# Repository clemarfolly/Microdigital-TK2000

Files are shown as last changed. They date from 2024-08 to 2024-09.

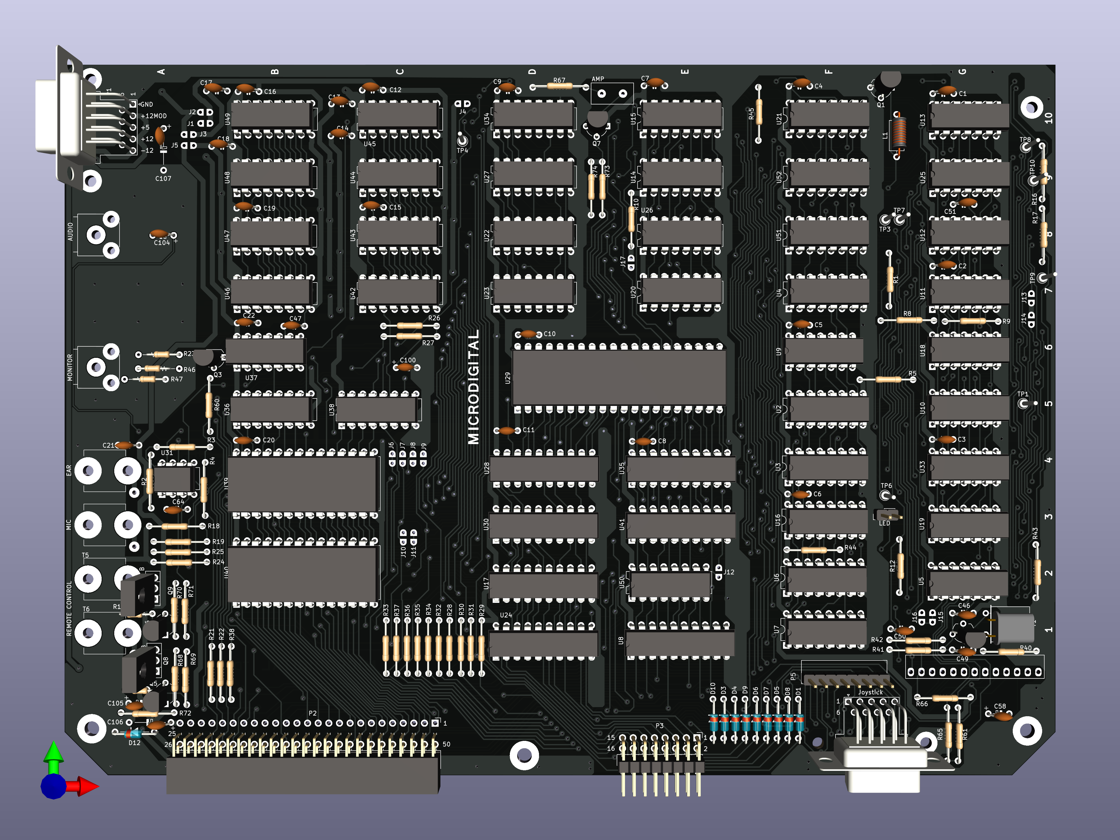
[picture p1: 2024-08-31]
Imagens/TK2000_f.png

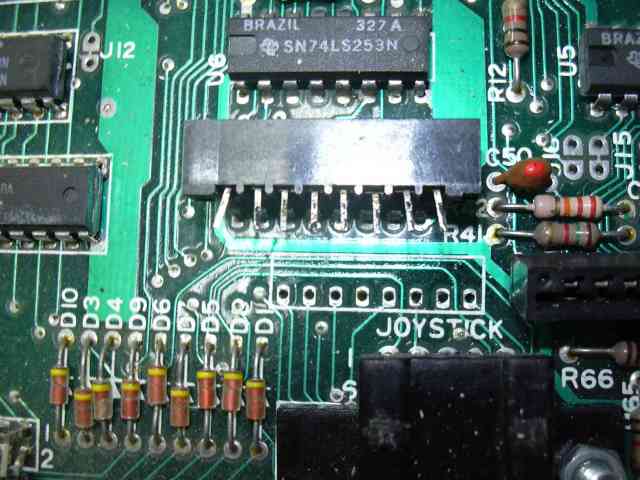
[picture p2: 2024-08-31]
Fotos/Original/6.jpg

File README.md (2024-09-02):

# Microdigital - TK2000

<p align="center">
    
</p>

A Microdigital Eletrônica Ltda foi uma das empresas pioneiras no mercado de microcomputadores no Brasil, tendo grande importância na popularização da informática durante a década de 1980. Fundada em 1979, a empresa se destacou por criar e distribuir uma série de microcomputadores compatíveis com modelos internacionais. A Microdigital se beneficiou da reserva de mercado imposta pelo governo brasileiro, o que levou a empresa a desenvolver produtos que atendessem à demanda interna por tecnologia, educação e entretenimento.

Entre os produtos está o TK2000, lançado oficialmente em 1984 após ser apresentado na Feira de Informática de 1983. Inspirado no Apple II, o TK2000 foi um microcomputador voltado para o mercado doméstico e educacional, parcialmente compatível com o software do Apple II, mas com algumas limitações em termos de hardware, o que o tornava mais acessível ao consumidor brasileiro. Equipado com uma CPU 6502, 16k de ROM e 64k de RAM, o TK2000 era, na verdade, um clone do Micro-Professor MPF-II, um modelo taiwanês fabricado pela Multitech (futura Acer). O sucesso do TK2000 consolidou a Microdigital como uma das líderes no mercado de microcomputadores no Brasil, contribuindo significativamente para a difusão da cultura computacional no país durante os anos 80. Em 1985, foi lançada uma versão aprimorada, o TK2000 II, que incluía uma opção de 128K de memória. O microcomputador foi descontinuado em 1987.

## Sobre essa reprodução

<p align="center">
    
</p>

A reprodução do projeto foi realizada sem acesso físico à placa original, com base em fotos encontradas na internet. Para isso, utilizou-se os software Sprint Layout e o KiCad para desenhar o esquema e a placa de circuito impresso. A réplica ainda não foi produzida, e seu funcionamento não foi validado. Agradecemos às pessoas que disponibilizaram as fotos e o esquema original, permitindo que esse trabalho fosse possível.

 ### Datalhes da placa
A placa é dupla face e o tamanho final ficou com 237x170 mm.

<p align="center">
  
  
</p>

### Comparação com a placa original
Embora eu não tenha tido acesso direto à placa original, me esforcei para que a recriação fosse a mais fiel possível. Algumas imagens de referência estavam em baixa resolução e precisaram ter suas proporções ajustadas, além de estarem com componentes e adesivos, o que dificultou a reprodução das trilhas que passavam por baixo deles.

<p align="center">
    
</p>

A parte de RF foi removida e no lugar colocada uma saída de áudio. Além disso, o jumper que conecta o pino 28 da ROM U39 ao pino 7 do 74LS244 foi integrado diretamente ao roteamento da placa, permetindo o uso de uma ROM 27C128.

### Para confecção

Na seção de releases desta página, você encontrará todos os arquivos necessários para a fabricação da placa: o gerber em formato zip, o esquema em PDF e a lista interativa de materiais em HTML. Basta enviar o arquivo zip para a sua fabricante de PCB de preferência.

### Chip customizado

A montagem requer a gravação de um chip PLD GAL16V8, o conteúdo está na pasta PAL. Mais detalhes em: 

https://www.facebook.com/groups/cidadedosclassicos/posts/5769043533153302/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

## Créditos

### Recriação da Placa: 

Clemar Folly Jr.

https://x.com/clemarfolly/ - https://www.facebook.com/clemarjr

### Fotos

Clube do TK90X

http://www.tk90x.com.br/Projetos_TK2000_clareamento.html

José Ferro - Recebido via E-mail

Tabajara Labs

http://tabalabs.com.br/tk2k/reparo_teclado/

Grupo Microdigital TK 2000 no Facebook

https://www.facebook.com/groups/2839171526116039/

Uma saída de som para o TK2000

https://www.victortrucco.com/TK/TK2000Som/TK2000Som

### Esquema

TK2000 - Esquema Elétrico Placa Principal - Datassette

https://datassette.org/manuais/hardware-tk-2000-microdigital-eletronica-manuais/tk2000-esquema-eletrico-placa-principal

#### Caso queira contribuir para que outras reproduções como esta sejam feitas, considere fazer uma doação.

Chave pix: clemarjr@gmail.com

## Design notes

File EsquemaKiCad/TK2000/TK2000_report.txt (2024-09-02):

PCB statistics report
=====================
- Date: 01/09/2024 15:54:08
- Project: TK2000
- Board name: TK2000

Board
-----
- Width: 236,8000 mm
- Height: 169,8100 mm
- Area: 40103,0117 mm²

Pads
----
- Through hole: 1244
- SMD: 0
- Connector: 0
- NPTH: 1

Vias
----
- Through vias: 583
- Blind/buried: 0
- Micro vias: 0

Components
----------

| | Front Side | Back Side | Total |
|---|---|---|---|
|THT: | 195 | 0 | 195 |
|SMD: | 0 | 0 | 0 |
|Unspecified:  | 9 | 2 | 11 |
|Total: | 204 | 2 | 206 |

Drill holes
-----------

| Count | Shape | X Size | Y Size | Plated | Via/Pad | Start Layer | Stop Layer |
|---|---|---|---|---|---|---|---|
| 958 | Round | 0,8000 mm | 0,8000 mm | PTH | Pad | F.Cu | B.Cu |
| 576 | Round | 0,6000 mm | 0,6000 mm | PTH | Via | F.Cu | B.Cu |
| 125 | Round | 1,0000 mm | 1,0000 mm | PTH | Pad | F.Cu | B.Cu |
| 106 | Round | 0,7000 mm | 0,7000 mm | PTH | Pad | F.Cu | B.Cu |
| 34 | Round | 0,7620 mm | 0,7620 mm | PTH | Pad | F.Cu | B.Cu |
| 8 | Round | 2,5000 mm | 2,5000 mm | PTH | Pad | F.Cu | B.Cu |
| 7 | Round | 0,8000 mm | 0,8000 mm | PTH | Via | F.Cu | B.Cu |
| 4 | Round | 2,7000 mm | 2,7000 mm | PTH | Pad | F.Cu | B.Cu |
| 4 | Round | 1,8000 mm | 1,8000 mm | PTH | Pad | F.Cu | B.Cu |
| 3 | Round | 3,5000 mm | 3,5000 mm | PTH | Pad | F.Cu | B.Cu |
| 2 | Round | 2,2000 mm | 2,2000 mm | PTH | Pad | F.Cu | B.Cu |
| 1 | Round | 2,7000 mm | 2,7000 mm | NPTH | Pad | F.Cu | B.Cu |

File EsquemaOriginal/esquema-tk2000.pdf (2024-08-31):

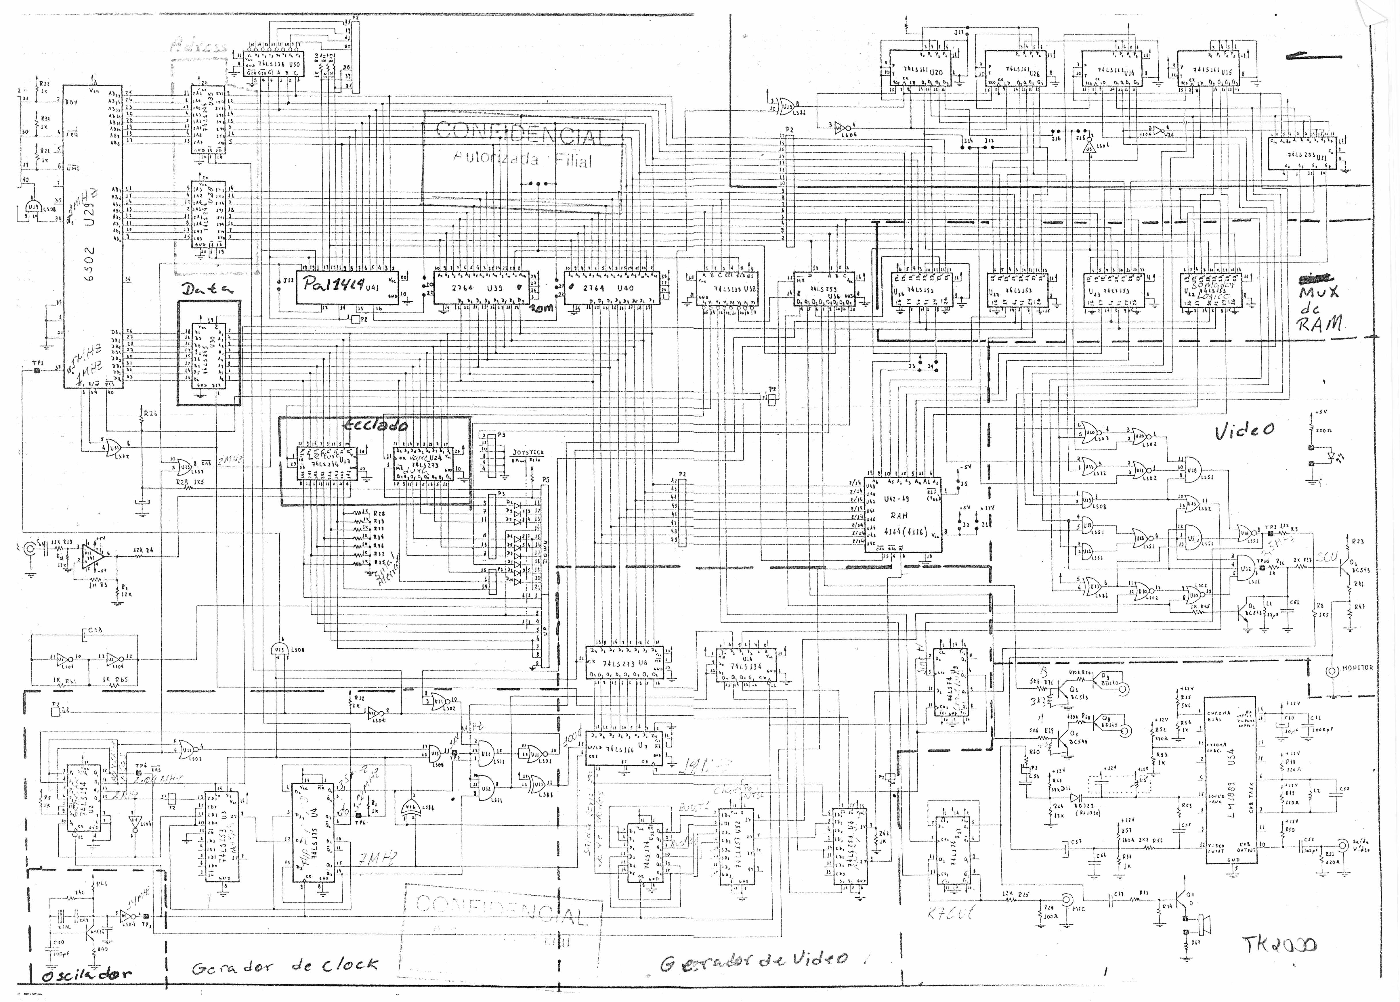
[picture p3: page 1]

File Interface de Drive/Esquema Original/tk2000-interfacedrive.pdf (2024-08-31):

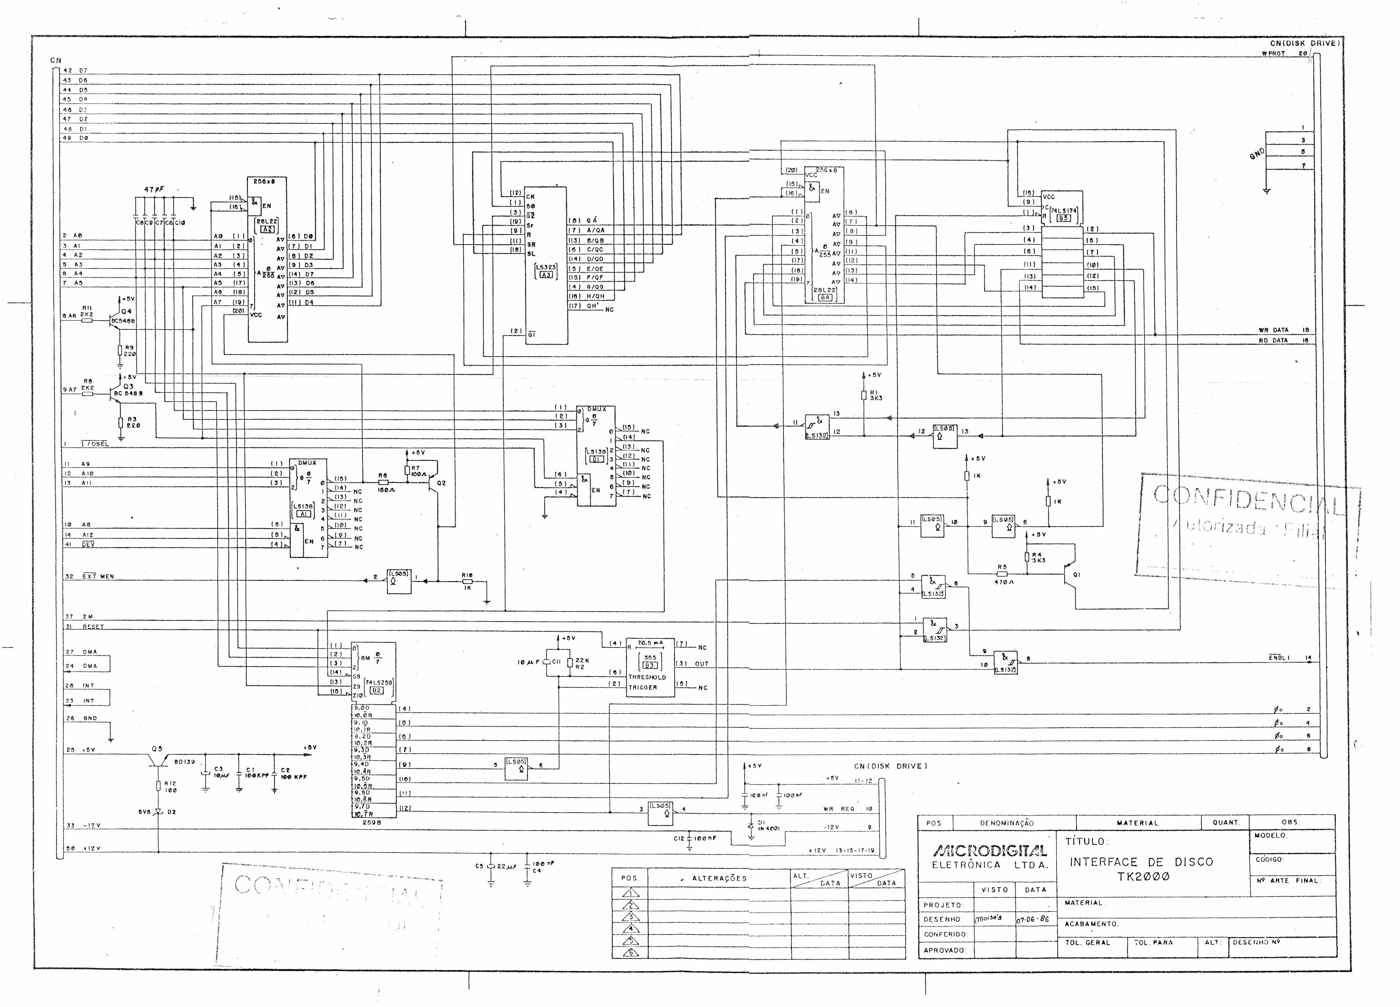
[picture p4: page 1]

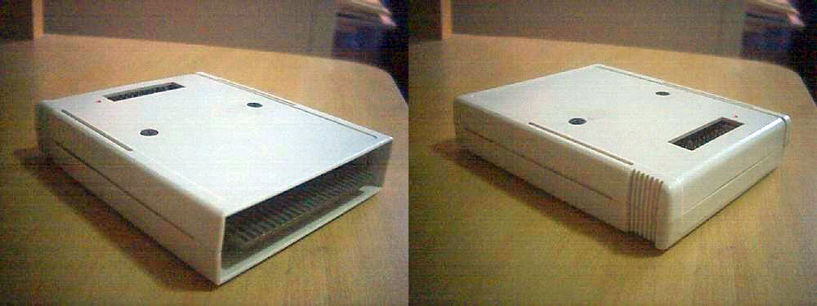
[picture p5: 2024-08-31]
Interface de Drive/Fotos/cartucho_interface.jpg

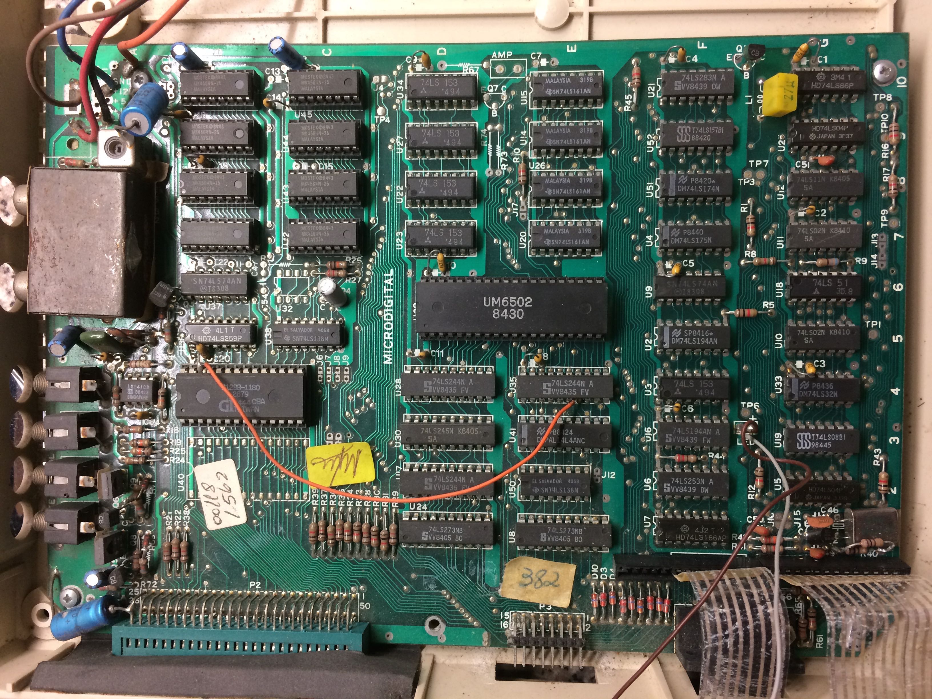
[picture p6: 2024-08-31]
Fotos/Original/tk2000-1.jpg

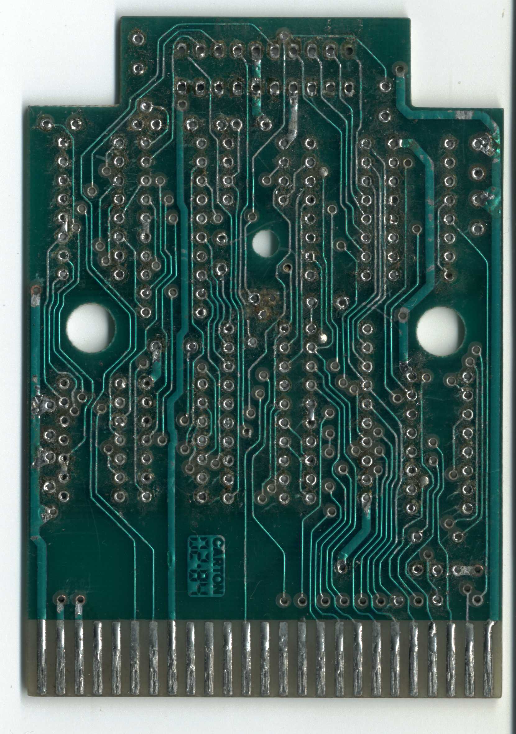
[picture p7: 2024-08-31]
Interface de Drive/Fotos/placa_drive_ls_vazia.jpg

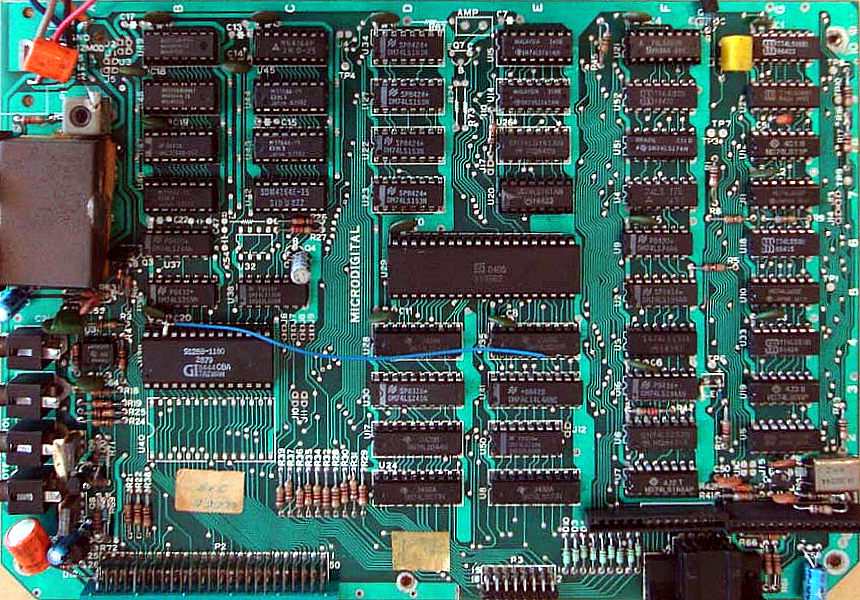
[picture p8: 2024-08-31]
Fotos/Corrigido/tk2000_pre_f.png

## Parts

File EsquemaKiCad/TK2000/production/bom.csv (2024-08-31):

Designator | Footprint | Quantity | Value | LCSC Part #
C1, C10, C11, C12, C13, C14, C15, C16, C17, C18, C19, C2, C20, C21, C22, C3, C4, C5, C6, C7, C8, C9 | C_Disc_D4.3mm_W1.9mm_P5.00mm | 22 | 0.1
C100, C58 | C_Polarized_P5.00mm | 2 | C_Polarized_Small
C104 | C_Polarized_P5.00mm | 1 | 1uF
C105 | C_Polarized_P5.00mm | 1 | 47uF
C106, C107 | C_Polarized_P10.00mm | 2 | 100uF
C46, C47, C49, C50, C51 | C_Disc_D4.3mm_W1.9mm_P5.00mm | 5 | C_Small
C64 | C_Disc_D4.3mm_W1.9mm_P5.00mm | 1 | ?
D1, D10, D3, D4, D5, D6, D7, D8, D9 | Diodo_9.38mm | 9 | D_Small
D12 | Diodo_9.38mm | 1 | 5V1
D13 | PinHeader_1x02_P2.54mm_Vertical | 1 | LED
H1, H2, H3 | MountingHole_3.5mm_Pad | 3 | MountingHole_Pad
H4, H6, H7, H8 | MountingHole_2.7mm_Pad | 4 | MountingHole_Pad
H5 | MountingHole_2.7mm | 1 | MountingHole_Pad
J1, J10, J14, J16, J3, J4, J5, J7, J9 | Jumper_Open | 9 | SolderJumper_2_Open
J100 | DSUB-9_Male_Horizontal_P2.77x2.54mm_EdgePinOffset9.40mm | 1 | Joystick
J11, J12, J6, J8 | Jumper_Bridged | 4 | SolderJumper_2_Open
J13, J15 | Jumper_Bridged | 2 | ~
J17 | Jumper_Open | 1 | SolderJumper_2_Open_Small
J2 | Jumper_Open | 1 | TK2000:Jumper_Open
L1 | L_Axial_L7.0mm_D3.3mm_P10.16mm_Horizontal_Fastron_MICC | 1 | 47uH
LS1 | Connector_AMP | 1 | AMP
P1 | DSUB-9_Male_Horizontal_P2.77x2.54mm_EdgePinOffset9.40mm | 1 | POWER
P2 | PinSocket_2x25_P2.54mm_Horizontal | 1 | Conector de Expansão
P3 | PinHeader_2x08_P2.54mm_Horizontal | 1 | P3
P5 | Connector_P5 | 1 | Conector_P5
Q1, Q3, Q5, Q6, Q7 | TO-92_Wide | 5 | BC548
Q2 | TO-92_Wide_Invert | 1 | BF494B
Q8, Q9 | TO-126-3_Vertical | 2 | BD140
R1, R10, R12, R16, R2, R21, R22, R26, R28, R29, R30, R31, R32, R33, R34, R35, R36, R37, R38, R43, R45, R5, R61, R65, R66 | Resistor_P12.7mm_Horizontal | 25 | 1k
R169, R171 | Resistor_P5.08mm_Vertical | 2 | 3k3
R17 | Resistor_P12.7mm_Horizontal | 1 | 2k
R18, R19, R25, R4, R9 | Resistor_P12.7mm_Horizontal | 5 | 12k
R23, R46, R47 | Resistor_P9.8mm_Horizontal | 3 | 1k
R24 | Resistor_P12.7mm_Horizontal | 1 | 100
R27, R8 | Resistor_P12.7mm_Horizontal | 2 | 1k5
R3 | Resistor_P12.7mm_Horizontal | 1 | 1M
R40, R41, R42 | Resistor_P12.7mm_Horizontal | 3 | 47
R44 | Resistor_P12.7mm_Horizontal | 1 | 220
R60 | Resistor_P12.7mm_Horizontal | 1 | 560
R67, R72, R73, R74 | Resistor_P12.7mm_Horizontal | 4 | ?
R68, R70 | Resistor_P12.7mm_Horizontal | 2 | 470
R69, R71 | Resistor_P12.7mm_Horizontal | 2 | 5k6
T2 | RCA_AV-8,4-5A | 1 | MONITOR
T3 | J2_Mono_Panel | 1 | EAR
T4 | J2_Mono_Panel | 1 | MIC
T5 | J2_Mono_Panel | 1 | B - Remote
T6 | J2_Mono_Panel | 1 | A - Remote
T7 | RCA_AV-8,4-5A | 1 | AUDIO
TP1, TP10, TP3, TP6, TP7, TP8, TP9 | Pin_D1.0mm_L10.0mm | 7 | TestPoint_Small
TP4 | Pin_D1.0mm_L10.0mm | 1 | ~{CAS}
U10, U11 | DIP-14_W7.62mm | 2 | 74LS02
U12 | DIP-14_W7.62mm | 1 | 74LS11
U13 | DIP-14_W7.62mm | 1 | 74LS86
U14, U15, U20, U26 | DIP-16_W7.62mm | 4 | 74LS161
U16, U2 | DIP-16_W7.62mm | 2 | 74LS194
U17, U28, U35 | DIP-20_W7.62mm | 3 | 74LS244
U18 | DIP-14_W7.62mm | 1 | 74LS51
U19 | DIP-14_W7.62mm | 1 | 74LS08
U21 | DIP-16_W7.62mm | 1 | 74LS283
U22, U23, U27, U3, U34 | DIP-16_W7.62mm | 5 | 74LS153
U24, U8 | DIP-20_W7.62mm | 2 | 74LS273
U25, U5 | DIP-14_W7.62mm | 2 | 74LS04
U29 | DIP-40_W15.24mm | 1 | 6502
U30 | DIP-20_W7.62mm | 1 | 74LS245
U31 | DIP-8_W7.62mm | 1 | LM741
U33 | DIP-14_W7.62mm | 1 | 74LS32
U36 | DIP-16_W7.62mm | 1 | 74LS259
U37, U9 | DIP-14_W7.62mm | 2 | 74LS74
U38, U50 | DIP-16_W7.62mm | 2 | 74LS138
U39, U40 | DIP-28_W15.24mm | 2 | 2764
U4 | DIP-16_W7.62mm | 1 | 74LS175
U41 | DIP-20_W7.62mm | 1 | PAL14L4
U42 | DIP-16_W7.62mm | 1 | 4116_U42
U43 | DIP-16_W7.62mm | 1 | 4116_U43
U44, U45, U46, U47 | DIP-16_W7.62mm | 4 | 4116_U47
U48, U49 | DIP-16_W7.62mm | 2 | 4116
U51 | DIP-16_W7.62mm | 1 | 74LS174
U52 | DIP-16_W7.62mm | 1 | 74LS157
U6 | DIP-16_W7.62mm | 1 | 74LS253
U7 | DIP-16_W7.62mm | 1 | 74LS166
Y1 | Crystal_HC52-U_Horizontal | 1 | Crystal

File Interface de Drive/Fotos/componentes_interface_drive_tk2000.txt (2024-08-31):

Q1 - BC558

Q2 - BC557

U1 - 74259

U2 - 7400

U3 - 555

U4 - 74174

U5 - 7405

não existe U6 no layout

U7 - 74138

U8 - N82S135N (PROM,256X8)

U9 - 74323

U10 - N82S135N (PROM,256X8)

U11 - 74138

C1 - 10uFx25V (lado positivo em R2)

C2 - 100nF (104)

C3 - 10uFx25V

C4 (próx. a U11) - 100nF (104)

C5 (próx. a U11) - 10uFx25V
C
4 (próx. a C6) - 47pF (470)

C5 (próx. a C6) - 47pF (470)

C6 - 47pF (470)
C7 - 47pF (470)

R1 - 3K3 (LR, LR, VM)

R2 - 22K (VM, VM, LR)

não existe R3 no layout

R4 - 3K3 (LR, LR, VM)

R5 - 470R (AM, RX, MR) 

R6 (próx. a U11) - 180
R (MR, CZ, MR)

R6 (próx. a R7) - vazio

R7 - 100R (MR, PT, MR)

não existe R8 no layout

não existe R9 no layout

R10 - 1K (MR, PT, VM)

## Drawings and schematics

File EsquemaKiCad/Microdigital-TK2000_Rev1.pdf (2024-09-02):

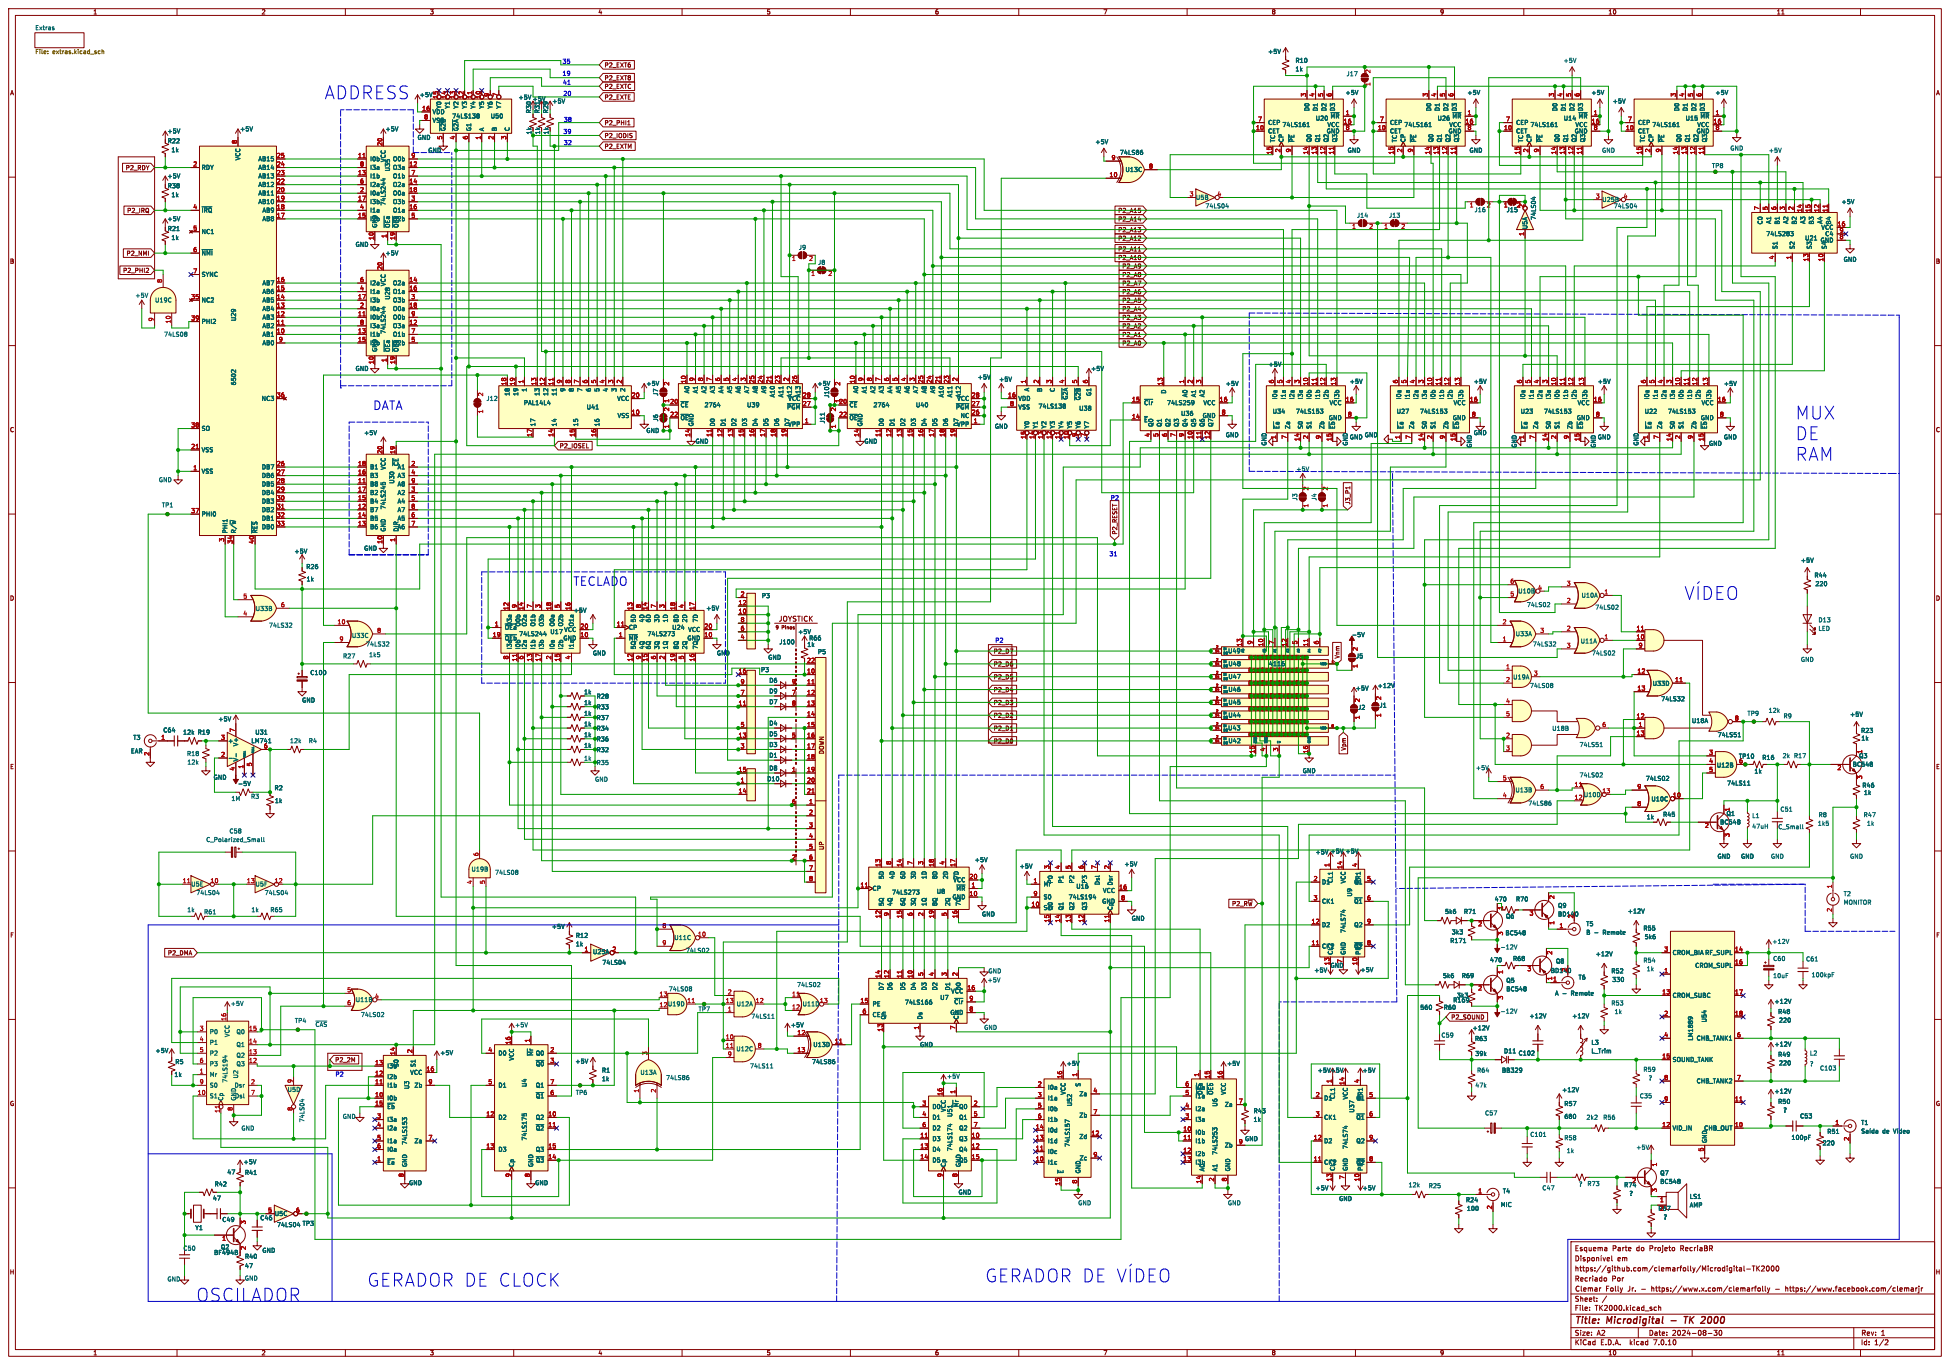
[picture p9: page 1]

3 DB3 30 DB2 31 DB1 32 DB0 33 R/~{W} 34 NC2 35 NC3 36 PHI0 37 SO 38 PHI2 39 ~{IRQ} 4 ~{RES} 40 NC1 5 ~{NMI} 6 SYNC 7 VCC

2 ~{CE} 20 A10 21 ~{OE} 22 A11 23 A9 24 A8 25 NC 26 ~{PGM} 27 VCC 28 A7

9 U22 74LS153 GND ~{Ea} 1 I0b 10 I1b 11 I2b 12 I3b 13 S0 14 ~{Eb} 15 VCC

þÿSaídae þÿVídeo GND

5 CE 6 Clk 7 GND 8 ~{Clr}9 Q1 BC548

5 CE 6 Clk 7 GND 8 ~{Clr} U7 9

8 Zb 9 GND U4 74LS175 ~{Mr}1 Q2 10 ~{Q2}11 D2 12 D3 13 ~{Q3}14 Q3 15 VCC 16 Q0 2 ~{Q0}3 D0 4 D1 5 ~{Q1}6 Q1 7 GND

8 Zc 9 +5V GND U51 74LS174 ~{Mr}1 Q3 10 D3 11 Q4 12 D4 13 D5 14 Q5 15 VCC 16 Q0 2 D0 3 D1 4 Q1 5 D2 6 Q2 7 GND

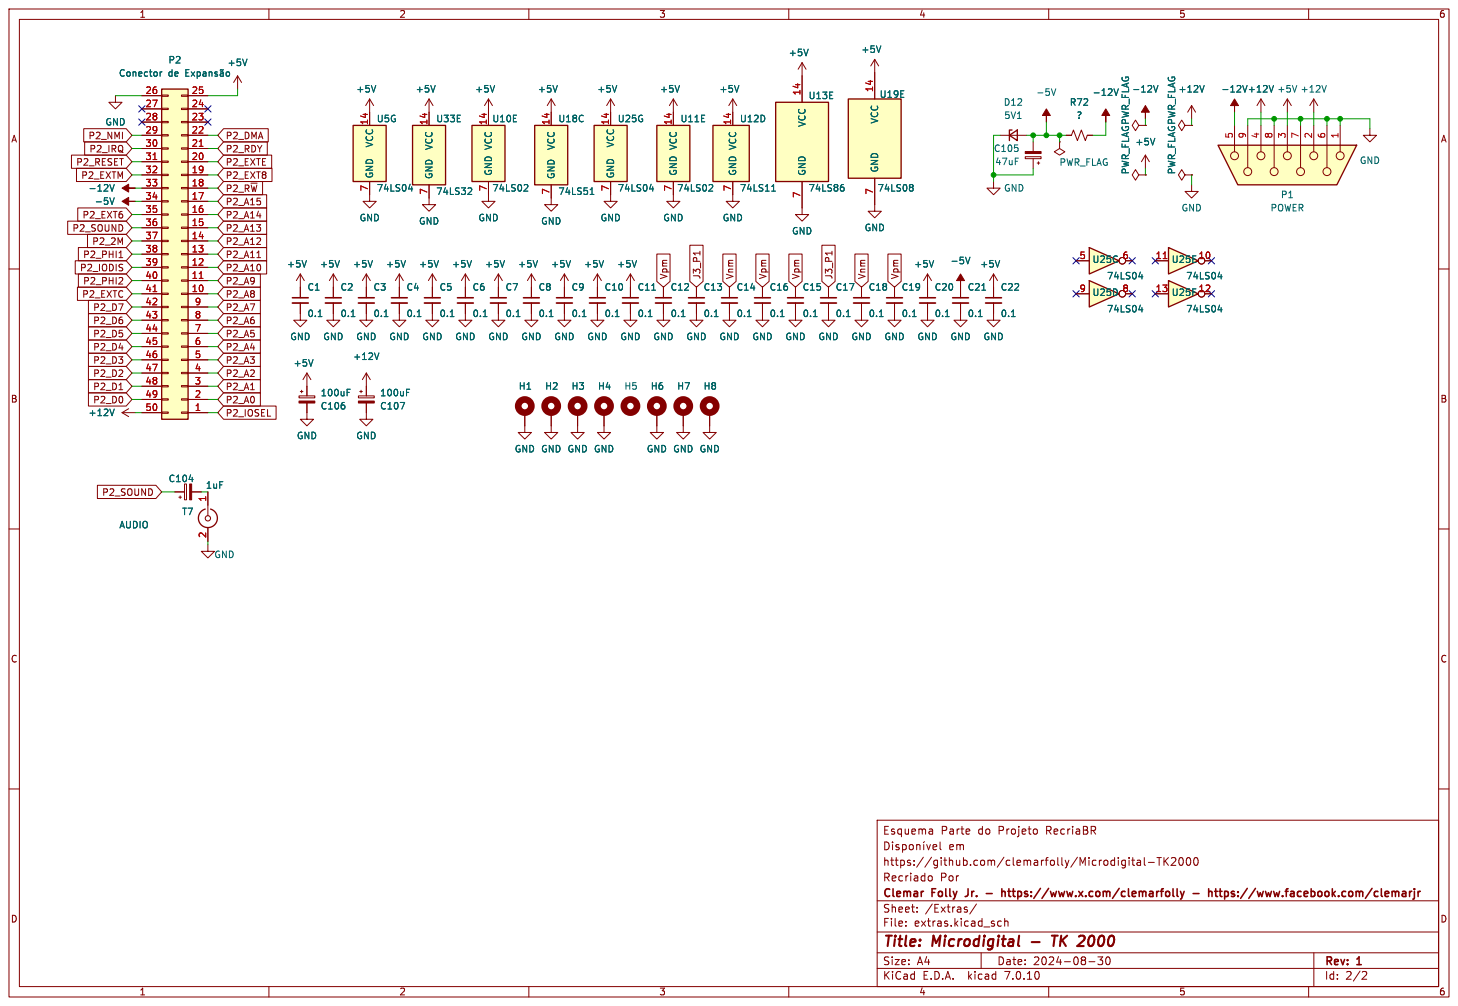
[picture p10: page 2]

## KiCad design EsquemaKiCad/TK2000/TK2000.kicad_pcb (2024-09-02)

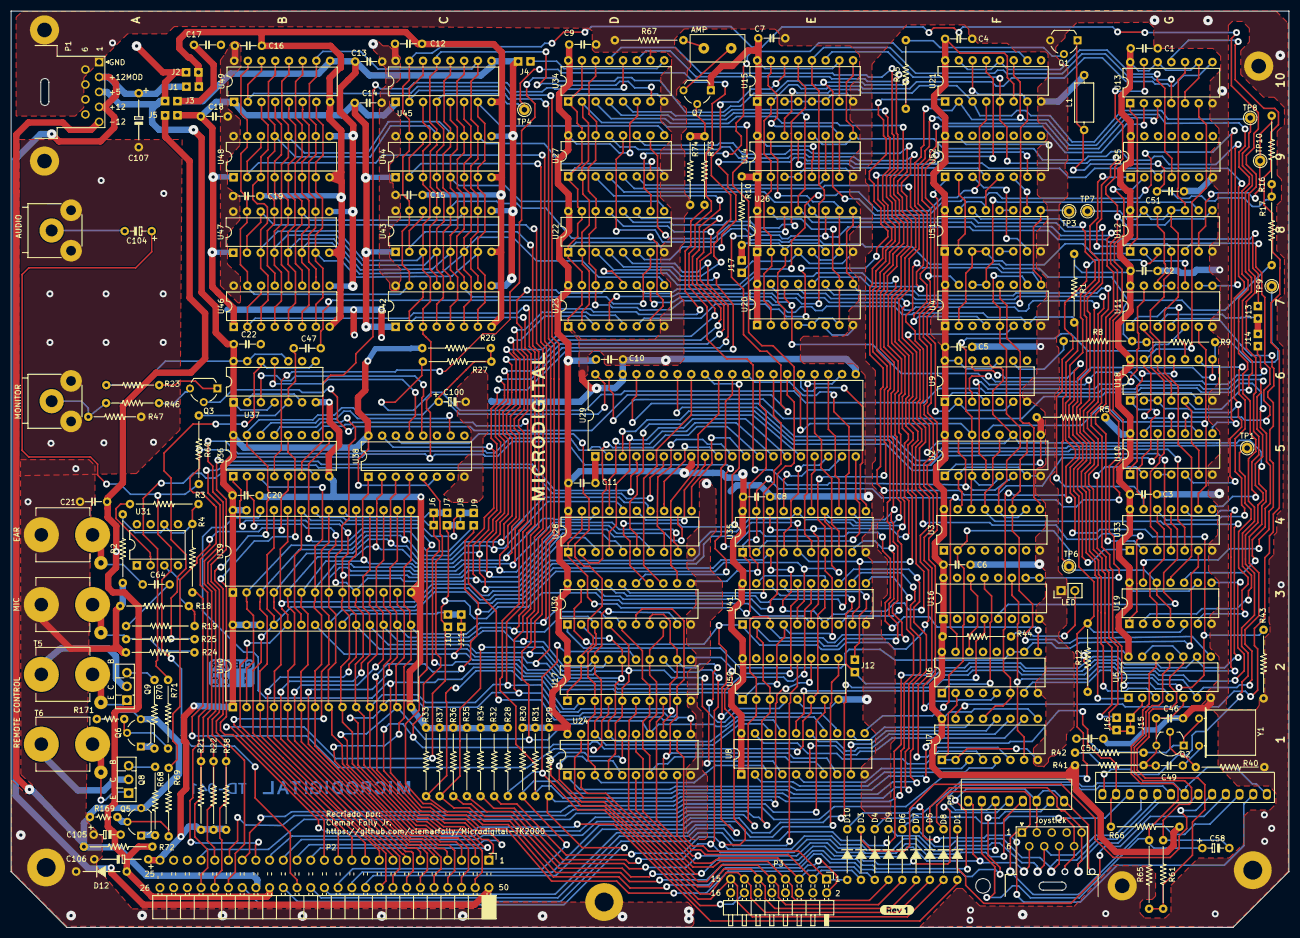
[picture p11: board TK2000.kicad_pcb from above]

Board: 2 copper layers, 236.8 x 169.8 mm, 204 parts (0 on the bottom side), 253 nets.

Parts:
C1, C2, C3, C4, C5, C6, C7, C8, C9, C10, C11, C12, C13, C14, C15, C16, C17, C18, C19, C20, C21, C22: 0.1; C_Disc_D4.3mm_W1.9mm_P5.00mm
C46, C47, C49, C50, C51: C_Small; C_Disc_D4.3mm_W1.9mm_P5.00mm
C58, C100: C_Polarized_Small; C_Polarized_P5.00mm
C64: ?; C_Disc_D4.3mm_W1.9mm_P5.00mm
C104: 1uF; C_Polarized_P5.00mm
C105: 47uF; C_Polarized_P5.00mm
C106, C107: 100uF; C_Polarized_P10.00mm
D1, D3, D4, D5, D6, D7, D8, D9, D10: D_Small; Diodo_9.38mm
D12: 5V1; Diodo_9.38mm
D13: LED; PinHeader_1x02_P2.54mm_Vertical
H1, H2, H3: MountingHole_Pad; MountingHole_3.5mm_Pad
H4, H6, H7, H8: MountingHole_Pad; MountingHole_2.7mm_Pad
H5: MountingHole_Pad; MountingHole_2.7mm
J1, J3, J4, J5, J7, J9, J10, J14, J16: SolderJumper_2_Open; Jumper_Open
J2: TK2000:Jumper_Open; Jumper_Open
J6, J8, J11, J12: SolderJumper_2_Open; Jumper_Bridged
J13, J15: Jumper_Bridged
J17: SolderJumper_2_Open_Small; Jumper_Open
J100: Joystick; DSUB-9_Male_Horizontal_P2.77x2.54mm_EdgePinOffset9.40mm
L1: 47uH; L_Axial_L7.0mm_D3.3mm_P10.16mm_Horizontal_Fastron_MICC
LS1: AMP; Connector_AMP
P1: POWER; DSUB-9_Male_Horizontal_P2.77x2.54mm_EdgePinOffset9.40mm
P2: Conector de Expansão; PinSocket_2x25_P2.54mm_Horizontal
P3: P3; PinHeader_2x08_P2.54mm_Horizontal
P5: Conector_P5; Connector_P5
Q1, Q3, Q5, Q6, Q7: BC548; TO-92_Wide
Q2: BF494B; TO-92_Wide_Invert
Q8, Q9: BD140; TO-126-3_Vertical
R1, R2, R5, R10, R12, R16, R21, R22, R26, R28, R29, R30, R31, R32, R33, R34, R35, R36, R37, R38, R43, R45, R61, R65, R66: 1k; Resistor_P12.7mm_Horizontal
R3: 1M; Resistor_P12.7mm_Horizontal
R4, R9, R18, R19, R25: 12k; Resistor_P12.7mm_Horizontal
R8, R27: 1k5; Resistor_P12.7mm_Horizontal
R17: 2k; Resistor_P12.7mm_Horizontal
R23, R46, R47: 1k; Resistor_P9.8mm_Horizontal
R24: 100; Resistor_P12.7mm_Horizontal
R40, R41, R42: 47; Resistor_P12.7mm_Horizontal
R44: 220; Resistor_P12.7mm_Horizontal
R60: 560; Resistor_P12.7mm_Horizontal
R67, R72, R73, R74: ?; Resistor_P12.7mm_Horizontal
R68, R70: 470; Resistor_P12.7mm_Horizontal
R69, R71: 5k6; Resistor_P12.7mm_Horizontal
R169, R171: 3k3; Resistor_P5.08mm_Vertical
T2: MONITOR; RCA_AV-8,4-5A
T3: EAR; J2_Mono_Panel
T4: MIC; J2_Mono_Panel
T5: B - Remote; J2_Mono_Panel
T6: A - Remote; J2_Mono_Panel
T7: AUDIO; RCA_AV-8,4-5A
TP1, TP3, TP6, TP7, TP8, TP9, TP10: TestPoint_Small; Pin_D1.0mm_L10.0mm
TP4: ~{CAS}; Pin_D1.0mm_L10.0mm
U2, U16: 74LS194; DIP-16_W7.62mm
U3, U22, U23, U27, U34: 74LS153; DIP-16_W7.62mm
U4: 74LS175; DIP-16_W7.62mm
U5, U25: 74LS04; DIP-14_W7.62mm
U6: 74LS253; DIP-16_W7.62mm
U7: 74LS166; DIP-16_W7.62mm
U8, U24: 74LS273; DIP-20_W7.62mm
U9, U37: 74LS74; DIP-14_W7.62mm
U10, U11: 74LS02; DIP-14_W7.62mm
U12: 74LS11; DIP-14_W7.62mm
U13: 74LS86; DIP-14_W7.62mm
U14, U15, U20, U26: 74LS161; DIP-16_W7.62mm
U17, U28, U35: 74LS244; DIP-20_W7.62mm
U18: 74LS51; DIP-14_W7.62mm
U19: 74LS08; DIP-14_W7.62mm
U21: 74LS283; DIP-16_W7.62mm
U29: 6502; DIP-40_W15.24mm
U30: 74LS245; DIP-20_W7.62mm
U31: LM741; DIP-8_W7.62mm
U33: 74LS32; DIP-14_W7.62mm
U36: 74LS259; DIP-16_W7.62mm
U38, U50: 74LS138; DIP-16_W7.62mm
U39, U40: 2764; DIP-28_W15.24mm
U41: PAL14L4; DIP-20_W7.62mm
U42: 4116_U42; DIP-16_W7.62mm
U43: 4116_U43; DIP-16_W7.62mm
U44, U45, U46, U47: 4116_U47; DIP-16_W7.62mm
U48, U49: 4116; DIP-16_W7.62mm
U51: 74LS174; DIP-16_W7.62mm
U52: 74LS157; DIP-16_W7.62mm
Y1: Crystal; Crystal_HC52-U_Horizontal
kibuzzard-66D4FA69: G***; kibuzzard-66D4FA69

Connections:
+5V: C1.1, C2.1, C3.1, C4.1, C5.1, C6.1, C7.1, C8.1, C9.1, C10.1, C11.1, C20.1, C22.1, C106.1, J2.2 (B), J3.2 (B), P1.3, P2.25, Q7.1 (C), R1.1, R5.2, R10.1, R12.1, R21.1, R22.1, R23.2, R26.1, R29.1, R30.1, R31.1, R38.1, R41.1, R44.2, R66.1, U2.16 (VCC), U3.16 (VCC), U4.1 (~Mr), U4.16 (VCC), U5.14 (VCC), U6.16 (VCC), U7.9 (~Clr), U7.16 (VCC), U8.1 (~MR), U8.20 (VCC), U9.1 (CL1), U9.4 (PR1), U9.10 (PR2), U9.13 (CL2), U9.14 (VCC), U10.14 (VCC), U11.14 (VCC), U12.14 (VCC), U13.5, U13.9, U13.12, U13.14 (VCC), U14.1 (~MR), U14.5 (D2), U14.16 (VCC), U15.1 (~MR), U15.7 (CEP), U15.10 (CET), U15.16 (VCC), U16.1 (Mr), U16.16 (VCC), U17.20 (VCC), U18.14 (VCC), U19.9, U19.14 (VCC), U20.1 (~MR), U20.16 (VCC), U21.6 (B1), U21.16 (VCC), U22.16 (VCC), U23.16 (VCC), U24.20 (VCC), U25.14 (VCC), U26.1 (~MR), U26.16 (VCC), U27.16 (VCC), U28.20 (VCC), U29.8 (VCC), U30.20 (VCC), U31.7 (V+), U33.14 (VCC), U34.6 (I0a), U34.16 (VCC), U35.20 (VCC), U36.16 (VCC), U37.1 (CL1), U37.4 (PR1), U37.10 (PR2), U37.13 (CL2), U37.14 (VCC), U38.6 (G1), U38.16 (VDD), U39.1 (VPP), U39.27 (~PGM), U39.28 (VCC), U40.1 (VPP), U40.26 (NC), U40.27 (~PGM), U40.28 (VCC), U41.20 (VCC), U50.16 (VDD), U51.1 (~Mr), U51.16 (VCC), U52.16 (VCC)
+12V: C107.1, J1.2 (B), P1.2, P1.4, P2.50
-5V: C21.1, C105.2, D12.2 (A), J5.2 (B), P2.34, R72.1, U31.4 (V-)
-12V: P1.5, P2.33, Q5.3 (E), Q6.3 (E), R72.2, R169.1, R171.2
GND: C1.2, C2.2, C3.2, C4.2, C5.2, C6.2, C7.2, C8.2, C9.2, C10.2, C11.2, C12.2, C13.2, C14.2, C15.2, C16.2, C17.2, C18.2, C19.2, C20.2, C21.2, C22.2, C46.2, C50.1, C51.2, C100.2, C105.1, C106.2, C107.2, D12.1 (K), D13.1 (K), H1.1, H2.1, H3.1, H4.1, H6.1, H7.1, H8.1, J17.1 (A), L1.2, P1.1, P1.6, P1.7, P1.8, P1.9, P2.26, P3.4, P3.6, P3.8, P3.10, P3.12, Q1.3 (E), R2.1, R18.1, R24.1, R28.1, R32.1, R33.1, R34.1, R35.1, R36.1, R37.1, R40.1, R43.2, R47.1, R67.1, R74.1, T2.2 (Ext), T3.2 (Ext), T4.2 (Ext), T7.2 (Ext), U2.2 (Dsr), U2.7 (Dsl), U2.8 (GND), U3.8 (GND), U3.15 (~Eb), U4.8 (GND), U5.7 (GND), U6.2 (A1), U6.8 (GND), U7.1 (Ds), U7.2 (D0), U7.8 (GND), U8.10 (GND), U9.7 (GND), U10.7 (GND), U11.7 (GND), U12.7 (GND), U13.7 (GND), U14.3 (D0), U14.4 (D1), U14.8 (GND), U15.3 (D0), U15.4 (D1), U15.5 (D2), U15.6 (D3), U15.8 (GND), U16.8 (GND), U17.10 (GND), U18.7 (GND), U19.7 (GND), U20.6 (D3), U20.8 (GND), U21.8 (GND), U22.1 (~Ea), U22.8 (GND), U22.15 (~Eb), U23.1 (~Ea), U23.8 (GND), U23.15 (~Eb), U24.10 (GND), U25.7 (GND), U26.4 (D1), U26.8 (GND), U27.1 (~Ea), U27.8 (GND), U27.15 (~Eb), U28.10 (GND), U29.1 (VSS), U29.21 (VSS), U29.38 (SO), U30.10 (GND), U33.7 (GND), U34.1 (~Ea), U34.8 (GND), U34.10 (I0b), U34.15 (~Eb), U35.10 (GND), U36.8 (GND), U37.7 (GND), U38.8 (VSS), U39.14 (GND), U40.14 (GND), U41.10 (VSS), U42.16 (GND), U43.16, U44.16, U45.16, U46.16, U47.16, U48.16, U49.16, U50.5 (~G2B), U50.8 (VSS), U51.8 (GND), U52.8 (GND), U52.15 (~E)
J3_P1: C13.1, C17.1, J3.1 (A), J4.1 (A), U42.9, U43.9, U44.9, U45.9, U46.9, U47.9, U48.9, U49.9
unnamed: C47.2, R73.1
unnamed: C49.1, Y1.1
unnamed: C58.1, P5.2, R65.2, U5.12
unnamed: C58.2, R61.1, U5.11
unnamed: C64.2, R19.2
unnamed: D1.2 (A), U36.12 (Q7)
unnamed: D1.1 (K), P5.18
unnamed: D3.2 (A), P3.3, U24.9 (4Q)
unnamed: D3.1 (K), P5.17
unnamed: D4.2 (A), P3.5, U24.15 (6Q)
unnamed: D4.1 (K), P5.15, P5.21
unnamed: D5.2 (A), P3.13, U24.5 (2Q)
unnamed: D5.1 (K), J100.5, P5.16
unnamed: D6.2 (A), P3.9, U24.2 (1Q)
unnamed: D6.1 (K), J100.9, P5.11
unnamed: D7.2 (A), P3.11, U24.19 (8Q)
unnamed: D7.1 (K), J100.8, P5.13
unnamed: D8.2 (A), P3.15, U24.16 (7Q)
unnamed: D8.1 (K), J100.1, P5.19
unnamed: D9.2 (A), P3.7, U24.6 (3Q)
unnamed: D9.1 (K), J100.7, P5.12
unnamed: D10.2 (A), P3.1, U24.12 (5Q)
unnamed: D10.1 (K), P5.20
unnamed: D13.2 (A), R44.1
unnamed: J4.2 (B), U34.9 (Zb)
unnamed: J6.1 (A), J6.2 (B), J7.1 (A), U39.20 (~CE), U39.22 (~OE), U41.15
unnamed: J10.1 (A), J11.1 (A), J11.2 (B), U40.20 (~CE), U40.22 (~OE), U41.16
unnamed: J12.1 (A), U41.17
unnamed: J12.2 (B), U33.10, U41.18
unnamed: J13.1 (A), J14.2 (B), U11.3
unnamed: J13.2 (B), U26.11 (Q3), U27.12 (I2b)
unnamed: J14.1 (A), U5.1, U20.14 (Q0), U23.10 (I0b)
unnamed: J15.1 (A), J15.2 (B), J16.2 (B), U5.2, U10.2
unnamed: J16.1 (A), U20.11 (Q3)
unnamed: J17.2 (B), R10.2, U20.3 (D0), U26.3 (D0), U26.6 (D3)
unnamed: LS1.2, R67.2
unnamed: P5.22, R27.2
unnamed: Q1.2 (B), R45.2
unnamed: C51.1, L1.1, Q1.1 (C), R16.2, R17.1
unnamed: C50.2, Q2.1 (B), R42.2, Y1.2
unnamed: C46.1, C49.2, Q2.3 (C), R41.2, R42.1, U5.5
unnamed: Q2.2 (E), R40.2
unnamed: Q3.2 (B), R8.2, R9.2, R17.2
unnamed: Q3.1 (C), R23.1
unnamed: Q3.3 (E), R46.2
unnamed: Q5.2 (B), R69.2 (K), R169.2
unnamed: Q5.1 (C), R68.2
unnamed: Q6.2 (B), R71.2 (K), R171.1
unnamed: Q6.1 (C), R70.1
unnamed: Q7.2 (B), R73.2, R74.2
unnamed: LS1.1, Q7.3 (E)
unnamed: Q8.3 (B), R68.1
unnamed: Q8.2 (C), T6.2 (Ext)
unnamed: Q8.1 (E), T6.1 (In)
unnamed: Q9.3 (B), R70.2
unnamed: Q9.2 (C), T5.2 (Ext)
unnamed: Q9.1 (E), T5.1 (In)
unnamed: R2.2, R3.2, R4.1, U31.6
unnamed: R16.1, TP10.1, U12.6
unnamed: R61.2, R65.1, U5.10, U5.13
unnamed: R46.1, R47.2, T2.1 (In)
unnamed: C64.1, T3.1 (In)
unnamed: R24.2, R25.2, T4.1 (In)
unnamed: C104.2, T7.1 (In)
unnamed: TP7.1, U12.10, U12.11, U12.13, U13.10, U19.11
unnamed: R5.1, U2.1 (Mr), U2.9 (S0)
unnamed: U2.3 (P0), U2.5 (P2), U2.14 (Q1), U3.14 (S0), U11.5, U22.2 (S1), U23.2 (S1), U27.2 (S1), U34.2 (S1)
unnamed: U2.4 (P1), U11.13
unnamed: TP4.1, U2.6 (P3), U2.15 (Q0), U42.4, U43.4, U44.4, U45.4, U46.4, U47.4, U48.4, U49.4
unnamed: U2.13 (Q2), U11.6, U33.9
unnamed: U2.10 (S1), U3.11 (I1b), U5.8
unnamed: U3.10 (I0b), U3.12 (I2b), U4.5 (D1), U4.10 (Q2)
unnamed: U3.9 (Zb), U4.12 (D2)
unnamed: U4.4 (D0), U13.3
unnamed: U4.13 (D3), U4.14 (~Q3), U12.9
unnamed: U4.2 (Q0), U12.1, U13.1, U51.3 (D0), U51.4 (D1)
unnamed: U4.15 (Q3), U7.6 (CE), U13.2
unnamed: R43.1, U6.7 (Za), U9.12 (D2)
unnamed: U7.3 (D1), U8.5 (2Q)
unnamed: U7.4 (D2), U8.19 (8Q)
unnamed: U7.5 (D3), U8.2 (1Q)
unnamed: U7.10 (D4), U8.6 (3Q)
unnamed: U7.11 (D5), U8.15 (6Q)
unnamed: U7.12 (D6), U8.9 (4Q)
unnamed: U7.14 (D7), U8.12 (5Q)
unnamed: U7.15 (PE), U13.11
unnamed: R9.1, TP9.1, U9.3 (CK1), U18.8
unnamed: R8.1, U9.9 (Q2)
unnamed: U10.1, U18.11
unnamed: U10.3, U10.4
unnamed: U10.10, U12.5
unnamed: U10.11, U13.6, U18.13
unnamed: U10.9, U10.13
unnamed: U11.1, U18.10
unnamed: U11.2, U33.3
unnamed: U11.4, U19.13
unnamed: U11.10, U12.2
unnamed: U11.11, U11.12, U12.12
unnamed: U12.3, U18.1, U18.6, U33.13
unnamed: U14.7 (CEP), U14.10 (CET), U15.15 (TC)
unnamed: U13.8, U14.2 (CP), U15.2 (CP), U20.2 (CP), U26.2 (CP)
unnamed: U14.6 (D3), U14.11 (Q3), U27.6 (I0a)
unnamed: TP8.1, U10.6, U14.14 (Q0), U18.5, U21.3 (A2)
unnamed: U10.5, U14.13 (Q1), U18.2, U18.3, U25.3
unnamed: U11.8, U11.9, U14.9 (~PE), U14.12 (Q2), U15.9 (~PE)
unnamed: U14.15 (TC), U26.5 (D2), U26.7 (CEP), U26.10 (CET)
unnamed: U15.14 (Q0), U22.4 (I2a)
unnamed: U15.13 (Q1), U22.12 (I2b)
unnamed: U13.4, U15.12 (Q2), U23.4 (I2a)
unnamed: U12.4, U15.11 (Q3), U18.4, U18.12, U21.5 (A1)
unnamed: TP3.1, U2.11 (Cp), U4.9 (Cp), U5.6, U7.7 (Clk), U9.11 (CK2), U16.11 (Cp), U51.9 (Cp)
unnamed: U8.16 (7Q), U16.4 (P1)
unnamed: U16.5 (P2), U33.11
unnamed: U6.14 (A0), U16.14 (Q1)
unnamed: U6.1 (~OEa), U16.13 (Q2)
unnamed: U12.8, U13.13, U16.9 (S0), U16.10 (S1)
unnamed: P5.7, R33.2, U17.2 (I0a)
unnamed: P5.3, P5.14, R32.2, U17.11 (I0b)
unnamed: R4.2, U17.4 (I1a)
unnamed: P5.5, R34.2, U17.13 (I1b)
unnamed: P5.4, R36.2, U17.6 (I2a)
unnamed: P3.14, R28.2, U17.15 (I2b)
unnamed: J100.6, P5.1, R35.2, U17.8 (I3a)
unnamed: J100.2, P5.6, P5.8, R37.2, U17.17 (I3b)
unnamed: U17.1 (~OEa), U17.19 (~OEb), U38.14 (Y1)
unnamed: U18.9, U19.3, U33.12
unnamed: U20.4 (D1), U20.5 (D2), U20.7 (CEP), U20.10 (CET), U26.15 (TC)
unnamed: U19.1, U20.13 (Q1), U21.7 (C0), U21.14 (A3)
unnamed: U19.2, U20.12 (Q2), U21.2 (B2), U21.11 (B4)
unnamed: U5.3, U20.15 (TC)
unnamed: U5.4, U20.9 (~PE), U26.9 (~PE)
unnamed: U21.12 (A4), U21.15 (B3), U25.4
unnamed: U21.4 (S1), U23.12 (I2b)
unnamed: U21.1 (S2), U23.6 (I0a)
unnamed: U21.13 (S3), U22.6 (I0a)
unnamed: U21.10 (S4), U22.10 (I0b)
unnamed: R1.2, TP6.1, U3.2 (S1), U4.7 (Q1), U8.11 (CP), U19.4, U19.12, U22.14 (S0), U23.14 (S0), U27.14 (S0), U34.14 (S0)
unnamed: U22.7 (Za), U42.11, U43.11, U44.11, U45.11, U46.11, U47.11, U48.11, U49.11
unnamed: U22.9 (Zb), U42.5, U43.5, U44.5, U45.5, U46.5, U47.5, U48.5, U49.5
unnamed: U23.7 (Za), U42.12, U43.12, U44.12, U45.12, U46.12, U47.12, U48.12, U49.12
unnamed: U23.9 (Zb), U42.6, U43.6, U44.6, U45.6, U46.6, U47.6, U48.6, U49.6
unnamed: U24.11 (CP), U38.15 (Y0)
unnamed: P5.10, R66.2, U24.1 (~MR)
unnamed: U26.14 (Q0), U27.10 (I0b)
unnamed: U26.13 (Q1), U33.2, U34.4 (I2a)
unnamed: U26.12 (Q2), U27.4 (I2a), U33.1
unnamed: U27.7 (Za), U42.10, U43.10, U44.10, U45.10, U46.10, U47.10, U48.10, U49.10
unnamed: U27.9 (Zb), U42.7, U43.7, U44.7, U45.7, U46.7, U47.7, U48.7, U49.7
unnamed: U28.2 (I0a), U29.13 (AB4)
unnamed: U28.11 (I0b), U29.12 (AB3)
unnamed: U28.4 (I1a), U29.15 (AB6)
unnamed: U28.13 (I1b), U29.10 (AB1)
unnamed: U28.6 (I2a), U29.16 (AB7)
unnamed: U28.15 (I2b), U29.9 (AB0)
unnamed: U28.8 (I3a), U29.11 (AB2)
unnamed: U28.17 (I3b), U29.14 (AB5)
unnamed: U6.15 (~OEb), U25.2, U28.1 (~OEa), U28.19 (~OEb), U35.1 (~OEa), U35.19 (~OEb)
unnamed: U29.17 (AB8), U35.15 (I2b)
unnamed: U29.18 (AB9), U35.4 (I1a)
unnamed: U29.19 (AB10), U35.17 (I3b)
unnamed: U29.20 (AB11), U35.2 (I0a)
unnamed: U29.22 (AB12), U35.6 (I2a)
unnamed: U29.23 (AB13), U35.13 (I1b)
unnamed: U29.24 (AB14), U35.8 (I3a)
unnamed: U29.25 (AB15), U35.11 (I0b)
unnamed: U29.33 (DB0), U30.13 (B6)
unnamed: U29.32 (DB1), U30.14 (B5)
unnamed: U29.31 (DB2), U30.12 (B7)
unnamed: U29.30 (DB3), U30.15 (B4)
unnamed: U29.29 (DB4), U30.17 (B2)
unnamed: U29.28 (DB5), U30.11 (B8)
unnamed: U29.27 (DB6), U30.16 (B3)
unnamed: U29.26 (DB7), U30.18 (B1)
unnamed: TP1.1, U19.6, U29.37 (PHI0)
unnamed: U29.3 (PHI1), U33.4
unnamed: U19.10, U29.39 (PHI2)
unnamed: U29.34 (R/~W), U33.5
unnamed: U6.10 (I0b), U6.11 (I1b), U30.1 (DIR), U33.6
unnamed: R18.2, R19.1, U31.3 (+)
unnamed: R3.1, U31.2 (-)
unnamed: U34.12 (I2b), U36.6 (Q2)
unnamed: U34.7 (Za), U42.13, U43.13, U44.13, U45.13, U46.13, U47.13, U48.13, U49.13
unnamed: R45.1, U10.8, U36.4 (Q0)
unnamed: R69.1, U36.5 (Q1)
unnamed: R71.1, U36.7 (Q3)
unnamed: P3.2, U36.9 (Q4)
unnamed: R31.2, U36.10 (Q5), U41.12
unnamed: U36.14 (~E), U38.10 (Y5)
unnamed: U37.3 (CK1), U38.12 (Y3)
unnamed: U37.11 (CK2), U38.13 (Y2)
unnamed: U37.2 (D1), U37.6 (~Q1)
unnamed: R25.1, U37.8 (~Q2), U37.12 (D2)
unnamed: C47.1, R60.1, U37.5 (Q1)
unnamed: U33.8, U42.15, U43.15, U44.15, U45.15, U46.15, U47.15, U48.15, U49.15
unnamed: U51.5 (Q1), U51.6 (D2)
unnamed: U51.11 (D3), U51.12 (Q4)
unnamed: U51.13 (D4), U51.15 (Q5), U52.5 (I0b)
unnamed: U6.6 (I0a), U7.13 (Qh), U51.14 (D5)
unnamed: U51.2 (Q0), U52.2 (I0a)
unnamed: U51.7 (Q2), U52.3 (I1a)
unnamed: U51.10 (Q3), U52.6 (I1b)
unnamed: U9.2 (D1), U9.6 (~Q1), U52.1 (S)
unnamed: U10.12, U52.4 (Za)
unnamed: U6.5 (I1a), U52.7 (Zb)
P2_2M: P2.37, U2.12 (Q3), U3.13 (I3b), U5.9
P2_A0: P2.2, U22.3 (I3a), U28.5 (O2b), U36.13 (D), U39.10 (A0), U40.10 (A0)
P2_A1: P2.3, U22.13 (I3b), U28.7 (O1b), U36.1 (A0), U39.9 (A1), U40.9 (A1)
P2_A2: P2.4, U23.3 (I3a), U28.12 (O3a), U36.2 (A1), U39.8 (A2), U40.8 (A2)
P2_A3: P2.5, U23.13 (I3b), U28.9 (O0b), U36.3 (A2), U39.7 (A3), U40.7 (A3)
P2_A4: P2.6, U23.5 (I1a), U28.18 (O0a), U38.1 (A), U39.6 (A4), U40.6 (A4)
P2_A5: P2.7, U22.5 (I1a), U28.3 (O3b), U38.2 (B), U39.5 (A5), U40.5 (A5)
P2_A6: P2.8, U22.11 (I1b), U28.16 (O1a), U38.3 (C), U39.4 (A6), U40.4 (A6)
P2_A7: P2.9, U27.3 (I3a), U28.14 (O2a), U38.4 (~G2A), U39.3 (A7), U40.3 (A7)
P2_A8: P2.10, U27.13 (I3b), U35.5 (O2b), U39.25 (A8), U40.25 (A8), U41.9
P2_A9: P2.11, U23.11 (I1b), U35.16 (O1a), U39.24 (A9), U40.24 (A9), U41.8
P2_A10: P2.12, U27.5 (I1a), U35.3 (O3b), U39.21 (A10), U40.21 (A10), U41.7
P2_A11: J7.2 (B), J8.1 (A), J8.2 (B), J9.2 (B), J10.2 (B), P2.13, U27.11 (I1b), U35.18 (O0a), U39.23 (A11), U40.23 (A11), U41.6
P2_A12: J9.1 (A), P2.14, U34.3 (I3a), U35.14 (O2a), U39.2 (A12), U40.2 (A12), U41.5
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

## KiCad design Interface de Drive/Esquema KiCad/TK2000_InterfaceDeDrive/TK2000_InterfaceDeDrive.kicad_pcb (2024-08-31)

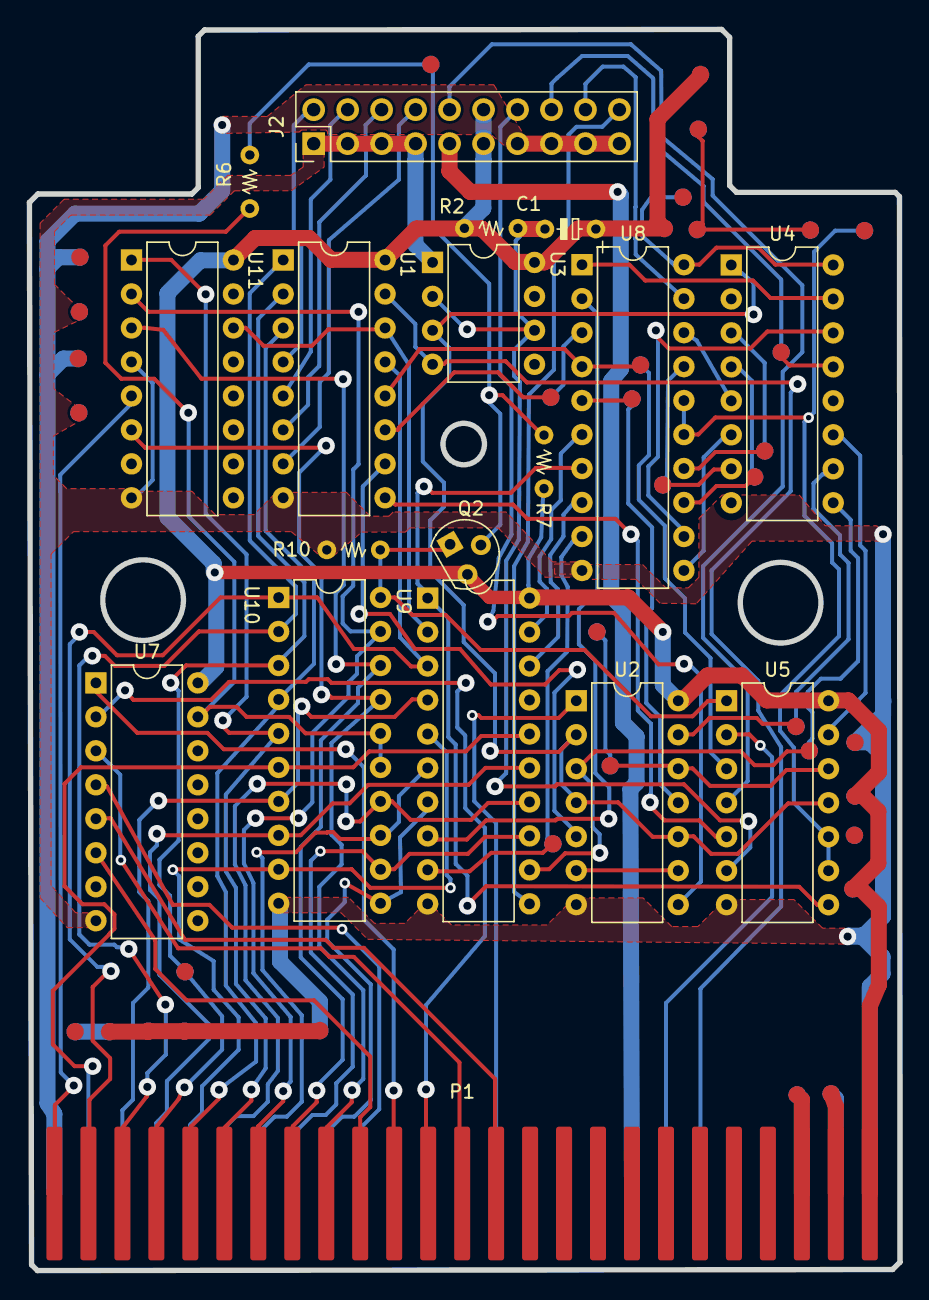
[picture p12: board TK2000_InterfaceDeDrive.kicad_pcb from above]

Board: 2 copper layers, 65.1 x 92.8 mm, 18 parts (0 on the bottom side), 51 nets.

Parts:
C1: 10uF; C_Polarized_P5.00mm
J2: CN (DISK DRIVE); PinSocket_2x10_P2.54mm_Vertical
P1: Conector de Expansão; Conector Edge
Q2: BC557; TO-92_Wide
R2: 22k; R_Axial_DIN0204_L3.6mm_D1.6mm_P4mm_Vertical
R6: 180; R_Axial_DIN0204_L3.6mm_D1.6mm_P4mm_Vertical
R7: 100; R_Axial_DIN0204_L3.6mm_D1.6mm_P4mm_Vertical
R10: 1k; R_Axial_DIN0204_L3.6mm_D1.6mm_P4mm_Vertical
U1: 74LS259; DIP-16_W7.62mm
U2: 74LS00; DIP-14_W7.62mm
U3: LM555xN; DIP-8_W7.62mm
U4: 74LS174; DIP-16_W7.62mm
U5: 74LS05; DIP-14_W7.62mm
U7, U11: 74LS138; DIP-16_W7.62mm
U8, U10: N82S135N; DIP-20_W7.62mm
U9: 74LS323; DIP-20_W7.62mm

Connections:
+5V: C1.1, J2.11, J2.12, P1.25, Q2.3 (E), R2.2, R7.2, U1.16 (VCC), U2.14 (VCC), U3.8 (VCC), U4.16 (VCC), U5.14 (VCC), U7.16 (VCC), U8.20 (VCC), U9.20 (VCC), U11.16 (VCC)
+12V: J2.13, J2.15, J2.17, J2.19, P1.50
-12V: J2.9, P1.33
/P2_2M: P1.37, U2.1
/P2_A0: P1.2, U1.13 (D), U9.3 (OE2), U10.1 (A0)
/P2_A1: P1.3, U1.1 (A0), U10.2 (A1)
/P2_A2: P1.4, U1.2 (A1), U10.3 (A2)
/P2_A3: P1.5, U1.3 (A2), U10.4 (A3)
/P2_A4: P1.6, U10.5 (A4), U11.1 (A0)
/P2_A5: P1.7, U10.19 (A7), U11.2 (A1)
/P2_A6: P1.8, U10.18 (A6), U11.3 (A2)
/P2_A7: P1.9, U10.17 (A5), U11.6 (E3)
/P2_A8: P1.10, U7.6 (E3)
/P2_A9: P1.11, U7.1 (A0)
/P2_A10: P1.12, U7.2 (A1)
/P2_A11: P1.13, U7.3 (A2)
/P2_A12: P1.14, U7.5 (E2)
/P2_D0: P1.49, U9.16 (IO7), U10.6 (O1)
/P2_D1: P1.48, U9.4 (IO6), U10.7 (O2)
/P2_D2: P1.47, U9.15 (IO5), U10.8 (O3)
/P2_D3: P1.46, U9.5 (IO4), U10.9 (O4)
/P2_D4: P1.45, U9.14 (IO3), U10.14 (O8)
/P2_D5: P1.44, U9.6 (IO2), U10.13 (O7)
/P2_D6: P1.43, U9.13 (IO1), U10.12 (O6)
/P2_D7: P1.42, U9.7 (IO0), U10.11 (O5)
/P2_EXTC: P1.41, U7.4 (E1)
/P2_EXTM: P1.32, U5.2
/P2_IOSEL: P1.1, U11.5 (E2)
/P2_RESET: P1.31, U1.15 (Clr), U3.4 (R)
/PHIO1: J2.2, U1.4 (Q0)
/PHIO2: J2.4, U1.5 (Q1)
/PHIO3: J2.6, U1.6 (Q2)
/PHIO4: J2.8, U1.7 (Q3)
/RD_DATA: J2.18, U8.19 (A7)
/U1_LATCH5: U1.10 (Q5), U2.5
/U3_OUT: U2.2, U2.4, U2.10, U3.3 (Q), U4.1 (~Mr), U5.11
/U3_OUT2: U5.8, U8.7 (O2), U9.1 (S0)
/U3_TRIGGER: C1.2, R2.1, U3.2 (TR), U3.6 (THR), U5.6
/U4_CLOCK: U2.3, U4.9 (Cp), U9.12 (Cp)
/U8_EN: U5.9, U5.10, U8.15 (~CE2), U8.16 (~CE1)
/U9_PIN8: U8.2 (A1), U9.8 (Q0)
/U10_EN: R6.1, U7.15 (O0), U10.15 (~CE2), U10.16 (~CE1)
/U10_VCC: Q2.1 (C), R10.2, U5.1, U10.20 (VCC)
/U11_PIN14: U1.14 (E), U9.2 (OE1), U11.14 (O1)
/WPROT: J2.20, U9.11 (DS0)
/WR_REQ: J2.10, U5.4
/~ENBL1: J2.14, U2.8
/~U3_TRIGGER: U1.9 (Q4), U5.5
GND: J2.1, J2.3, J2.5, J2.7, P1.26, R10.1, U1.8 (GND), U2.7 (GND), U3.1 (GND), U4.8 (GND), U5.7 (GND), U7.8 (GND), U8.10 (GND), U9.10 (GND), U10.10 (GND), U11.4 (E1), U11.8 (GND)
unnamed: Q2.2 (B), R6.2, R7.1
unnamed: U2.6, U2.9

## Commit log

2024-08-31 Primeira versão no github
    [DISKII-1.csv, DISKII-2.csv, TK2000.kicad_pcb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]
2024-09-02 Finalização da Revisão 1
    [TK2000.kicad_pcb, TK2000.kicad_sch, designators.csv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]
2026-10-18 Revisao 2: diodos em serie com R69/R71
    Na placa original cada resistor de 5k6 (R69/R71) tem um diodo soldado
    em serie. O footprint dos resistores passou para
    Resistor_P5.08mm_Vertical e o lugar dos diodos foi incluido na PCB,
    com a orientacao dos diodos corrigida.
    - novo simbolo TK2000:D_Small e novo footprint TK2000:Diodo_5.715mm
    - D69 e D71 (1N4148) adicionados em serie com R69 e R71
    - arquivos de fabricacao da rev 2 (gerbers e BOM interativa)
    - README da pasta Fabricacao
